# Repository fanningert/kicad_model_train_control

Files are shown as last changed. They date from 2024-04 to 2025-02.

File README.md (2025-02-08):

# Model Train Control

Control unit for analog model trains, based on ESPHome. A Home Assistant instance is used for visualization and control. This board is stackable up to 64 boards and every board has 16 outputs (3 pin). The Voltage is limited on the outputs per ESPHome template.
It comes in three variants, but all variants are the same boards. Only some components are not placed.

* Primary node with ESP32-S3-Wroom-2
* Primary node with ESP32-Devkit (can also be used as sub node with 3,3V power supply and protection)
* Sub node

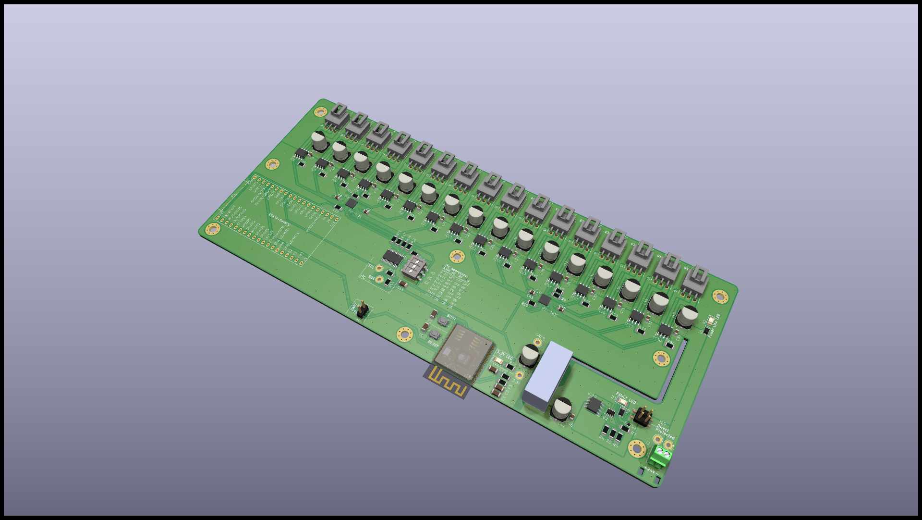
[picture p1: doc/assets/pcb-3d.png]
3D render of PCB

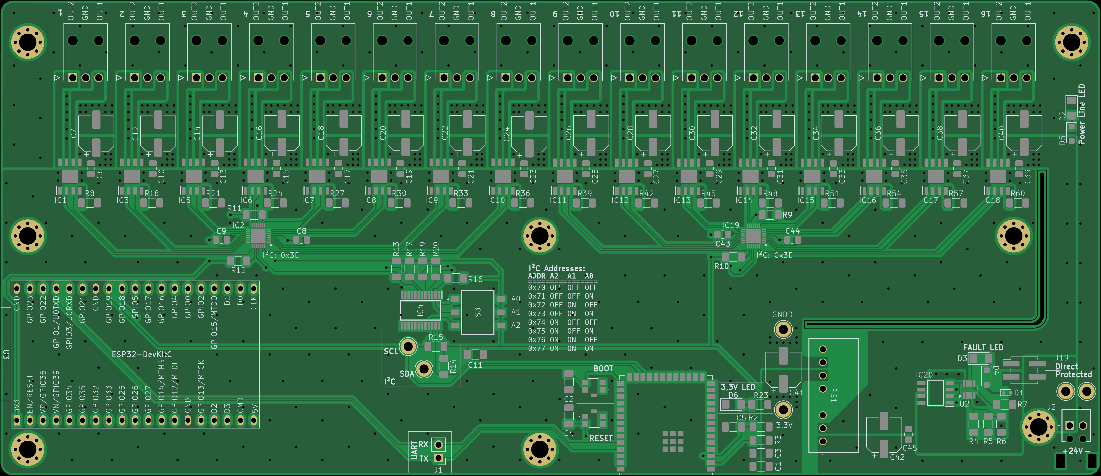
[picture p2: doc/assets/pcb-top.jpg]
PCB Top

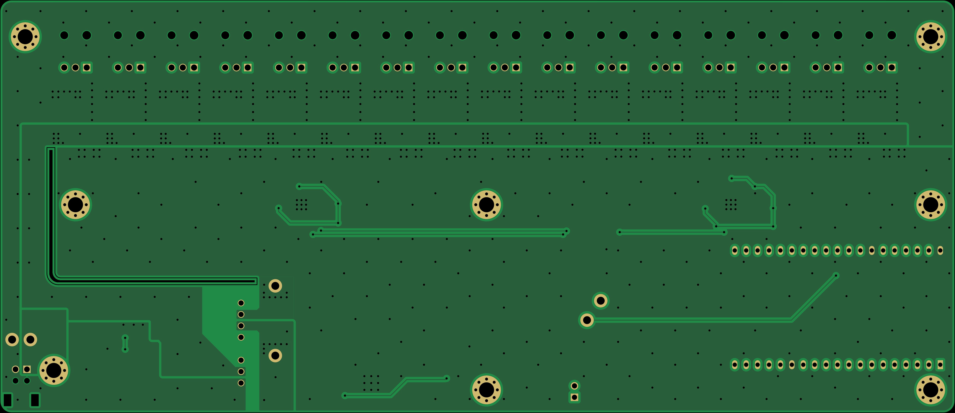
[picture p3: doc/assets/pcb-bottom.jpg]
PCB Bottom


## Features

* 16 h-bridges per board and stackable to 64 boards
* Reverse Voltage, Over Voltage and Under Voltage protection
* (optional) ESP32-Devkit
* (optional) ESP32-S3-Wroom-2

## Simple graphic of the board connections

```mermaid
flowchart LR
    Z[PowerSupply] ===|24V DC| A
    A[PCB_Core1] ===|24V DC, 3.3V, I2C| B & C & D
    B[PCB_Core2]
    C[PCB_Core...]
    D[PCB_Core64]
```

## Supported szenarios

- Power line
- Yield
- Generic Switch
- Signal
- Uncoupler

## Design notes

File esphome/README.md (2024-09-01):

# Model Train Control - ESPHome configuration examples

There is a non linear curve for the voltage control. On step line from 0 to 5V in the first 5% and then a linear line up to the input voltage. One side effect of DRV8871DDA.

Input voltage: 24V DC
| Percent | Output Voltage |
|---|---|
| 0 | 0 |
| 10 | 6,5 V |
| 20 | 8,6 V |
| 30 | 10,7 V |
| 40 | 12,6 V |
| 50 | 14,6 V |
| 60 | 16,5 V |
| 70 | 18,4 V |
| 80 | 20,1 V |
| 90 | 22 V |
| 100 | 24 V |

For example, when you need 16V I selected 0,58 (58%) for the voltage_multi parameter.

## Templates

### Board

The central component for ESPHome usage. This create some internal components with unique IDs. When you stack the boards, you need to add one entry for every board with a unique board number.

Parameter:

* hub_no = every stack get it's unique id
* board_no = every board in the same stack get it's unique id

Usable output IDs like h1b1p1.
h = hub, b = board, p = Board Port

```yaml
packages:
  board1: !include
    file: common/mtc_ha_board.yaml
    vars:
      hub_no: 1
      board_no: 1
      i2c_address: "0x70"
  board2: !include
    file: common/mtc_ha_board.yaml
    vars:
      hub_no: 1
      board_no: 2
      i2c_address: "0x71"
```

### Power line

A simple H-Bridge to control the railway power of the train.

```yaml
packages:
  train01: !include
    file: common/mtc_ha_power_line.yaml
    vars:
      hub_no: ${hub_no}
      board_no: "1"
      port_no: "01"
      voltage_multi: 0.58
```

### Yield

```yaml
packages:
  yield01: !include
    file: common/mtc_ha_yield.yaml
    vars:
      hub_no: 1
      board_no: "1"
      port_no: "02"
      voltage_multi: 0.58
```

### Generic Switch

```yaml
packages:
  switch01: !include
    file: common/mtc_ha_switch.yaml
    vars:
      hub_no: 1
      board_no: "1"
      port_no: "03"
      voltage_multi: 0.58
```

### Signal

```yaml
packages:
  signal01: !include
    file: common/mtc_ha_signal.yaml
    vars:
      hub_no: 1
      board_no: "1"
      port_no: "04"
      voltage_multi: 0.58
```

### Decoupler

```yaml
packages:
  decoupler01: !include
    file: common/mtc_ha_decoupler.yaml
    vars:
      hub_no: 1
      board_no: "1"
      port_no: "05"
      voltage_multi: 0.58
```

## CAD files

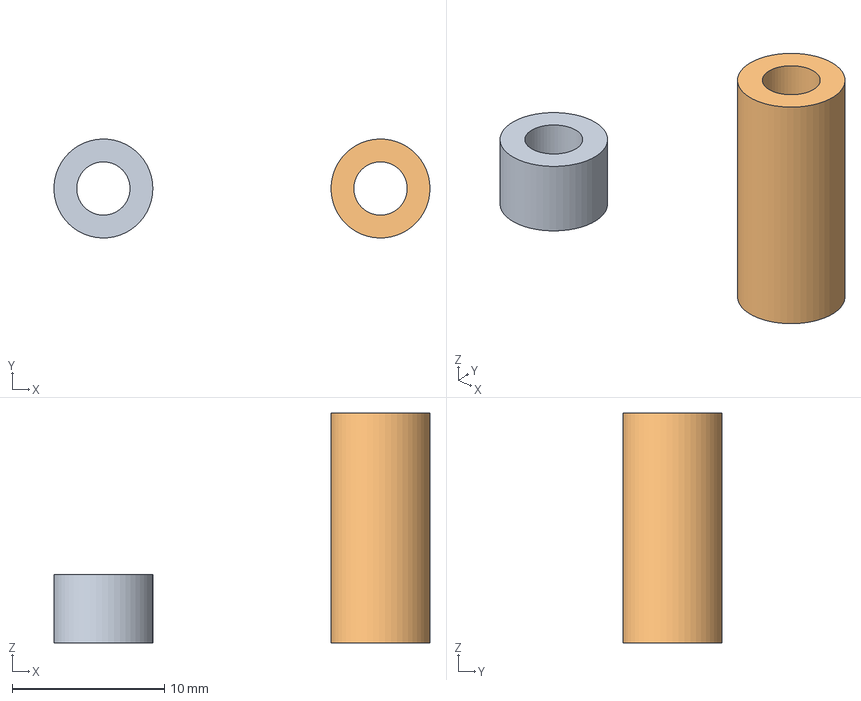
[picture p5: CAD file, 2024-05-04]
3dcase/case-Spacer.step
24.7 x 6.50 x 15.1 mm
Körper027
Körper032

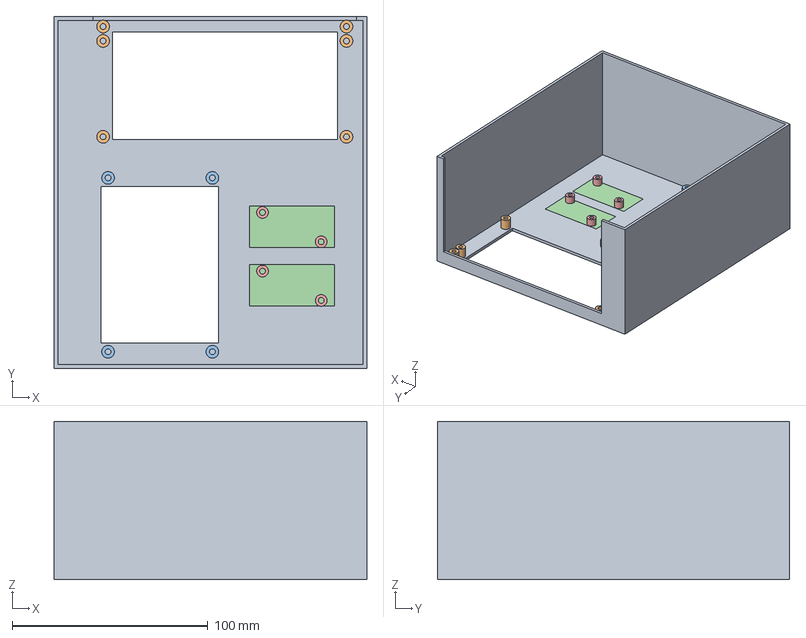
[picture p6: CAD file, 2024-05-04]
3dcase/case.step
160.0 x 180.0 x 81.0 mm
Körper007
Körper001
Körper002
Körper003
Körper004
Körper005
Körper006
Körper009
Körper010
Körper011
Körper012
Körper013
Körper014
Körper015
Körper016
Körper017
Körper018

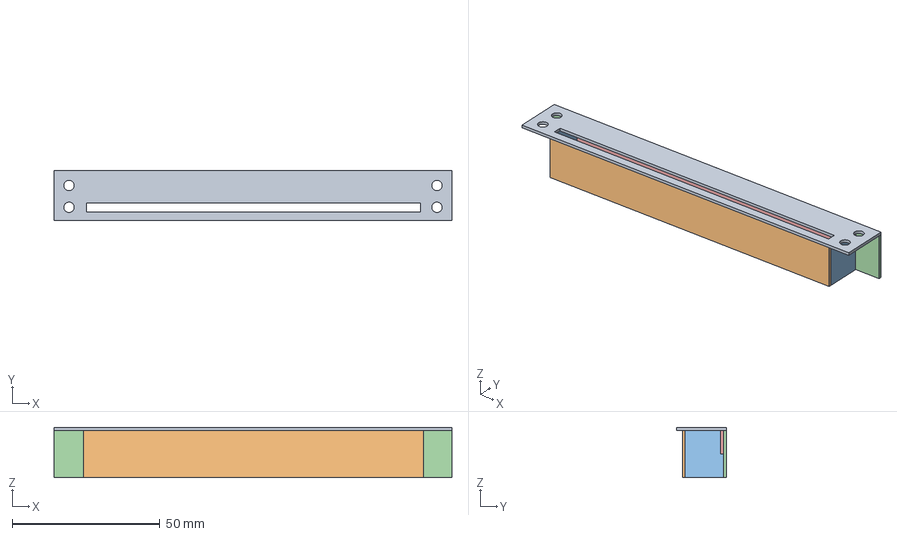
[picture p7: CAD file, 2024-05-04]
3dcase/case-PCBPlaceholder.step
134.6 x 17.0 x 17.0 mm
Körper020
Körper
Körper028
Körper029
Körper030
Körper031
Körper033

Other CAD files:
3dcase/case.FCStd

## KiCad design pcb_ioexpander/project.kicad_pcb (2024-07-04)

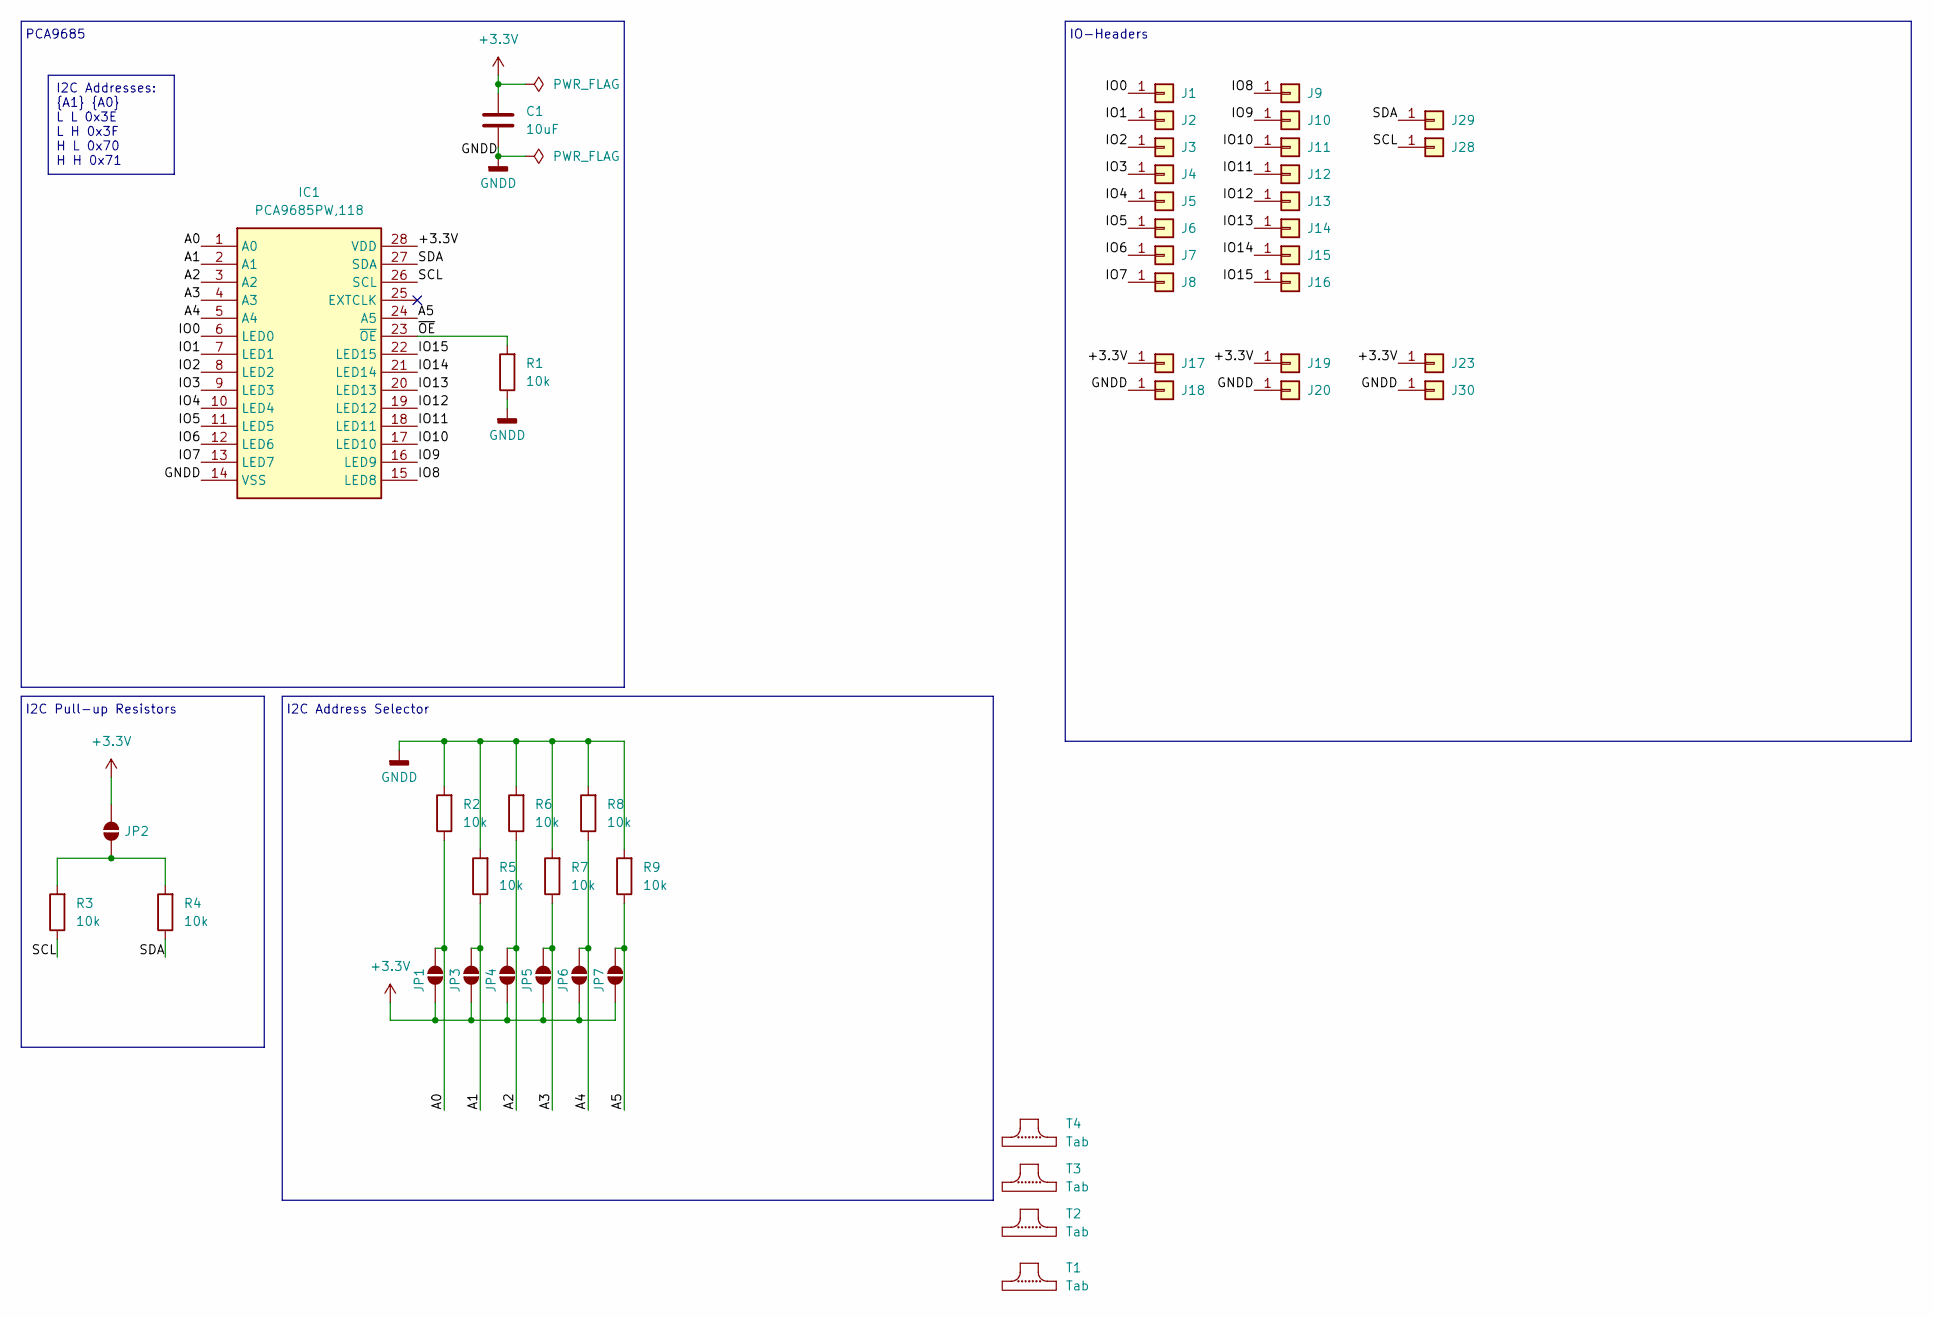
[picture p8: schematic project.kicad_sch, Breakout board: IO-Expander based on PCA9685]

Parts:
C1: 10uF; C_0402_1005Metric_Pad0.74x0.62mm_HandSolder
IC1: PCA9685PW,118; SOP65P640X110-28N; Mouser Part Number 771-PCA9685PW,118
J1, J2, J3, J4, J5, J6, J7, J8, J9, J10, J11, J12, J13, J14, J15, J16, J17, J18, J19, J20, J23, J28, J29, J30: Castellated_Hole02
JP1, JP2, JP3, JP4, JP5, JP6, JP7: SolderJumper_2_Open; SolderJumper-2_P1.3mm_Open_TrianglePad1.0x1.5mm
R1, R2, R3, R4, R5, R6, R7, R8, R9: 10k; R_0402_1005Metric_Pad0.72x0.64mm_HandSolder
T1, T2, T3, T4: Tab

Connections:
+3.3V: C1.1, IC1.28 (VDD), J17.1, J19.1, J23.1, JP1.2 (B), JP2.2 (B), JP3.2 (B), JP4.2 (B), JP5.2 (B), JP6.2 (B), JP7.2 (B)
/A0: IC1.1 (A0), JP1.1 (A), R2.1
/A1: IC1.2 (A1), JP3.1 (A), R5.1
/A2: IC1.3 (A2), JP4.1 (A), R6.1
/A3: IC1.4 (A3), JP5.1 (A), R7.1
/A4: IC1.5 (A4), JP6.1 (A), R8.1
/A5: IC1.24 (A5), JP7.1 (A), R9.1
/IO0: IC1.6 (LED0), J1.1
/IO1: IC1.7 (LED1), J2.1
/IO2: IC1.8 (LED2), J3.1
/IO3: IC1.9 (LED3), J4.1
/IO4: IC1.10 (LED4), J5.1
/IO5: IC1.11 (LED5), J6.1
/IO6: IC1.12 (LED6), J7.1
/IO7: IC1.13 (LED7), J8.1
/IO8: IC1.15 (LED8), J9.1
/IO9: IC1.16 (LED9), J10.1
/IO10: IC1.17 (LED10), J11.1
/IO11: IC1.18 (LED11), J12.1
/IO12: IC1.19 (LED12), J13.1
/IO13: IC1.20 (LED13), J14.1
/IO14: IC1.21 (LED14), J15.1
/IO15: IC1.22 (LED15), J16.1
/SCL: IC1.26 (SCL), J28.1, R3.1
/SDA: IC1.27 (SDA), J29.1, R4.1
/~OE: IC1.23 (~OE), R1.2
GNDD: C1.2, IC1.14 (VSS), J18.1, J20.1, J30.1, R1.1, R2.2, R5.2, R6.2, R7.2, R8.2, R9.2
unnamed: JP2.1 (A), R3.2, R4.2

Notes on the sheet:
I2C Addresses: {A1} {A0} L L 0x3E L H 0x3F H L 0x70 H H 0x71
IO-Headers
I2C Address Selector
I2C Pull-up Resistors
PCA9685

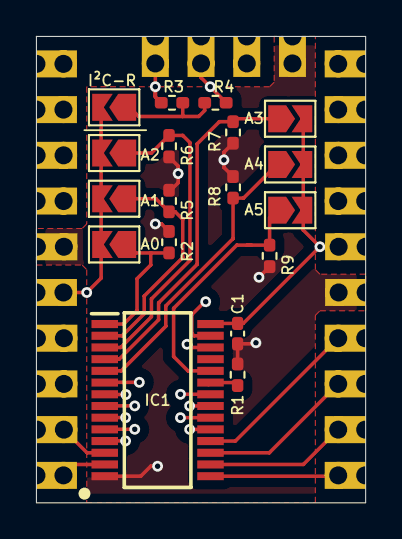
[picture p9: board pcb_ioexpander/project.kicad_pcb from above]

Board: 4 copper layers, 18.3 x 25.9 mm, 47 parts (1 on the bottom side), 28 nets.

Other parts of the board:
QR*****: https://github.com/fanningert/kicad_pcb_ioexpander; //github.com/fanningert/kicad_pcb_ioexpander

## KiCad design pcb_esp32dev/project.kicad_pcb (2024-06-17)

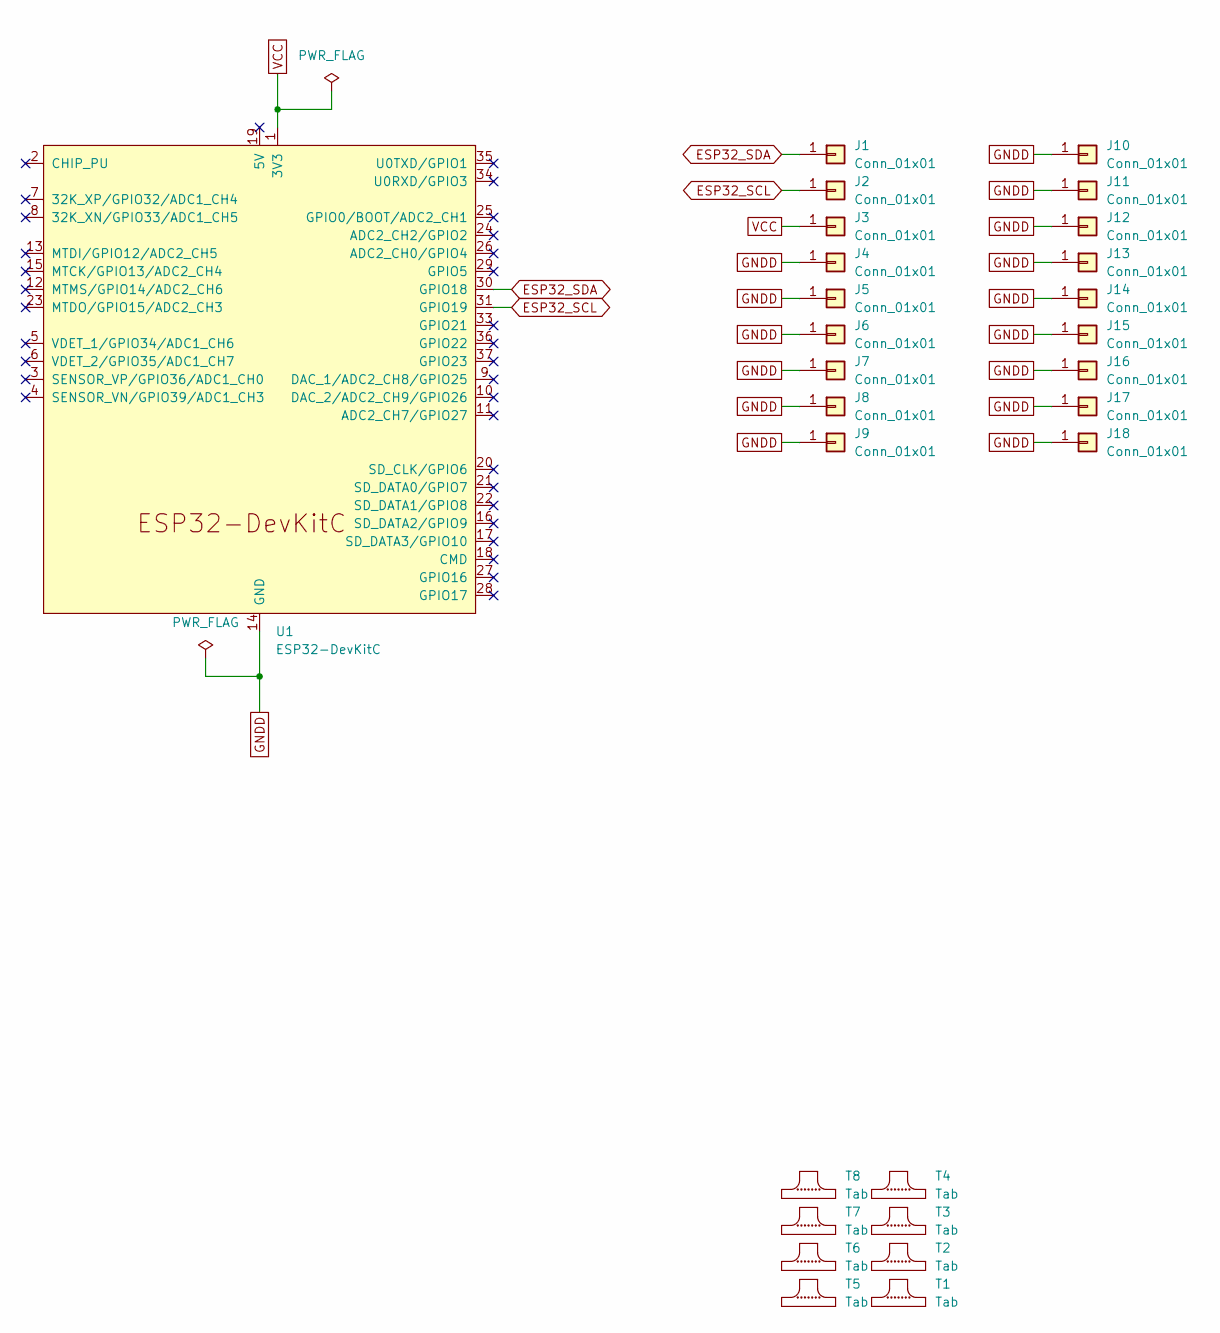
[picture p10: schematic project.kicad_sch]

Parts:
J1, J2, J3, J4, J5, J6, J7, J8, J9, J10, J11, J12, J13, J14, J15, J16, J17, J18: Conn_01x01; Castellated_Hole02
T1, T2, T3, T4, T5, T6, T7, T8: Tab
U1: ESP32-DevKitC

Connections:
ESP32_SCL: J2.1, U1.31 (GPIO19)
ESP32_SDA: J1.1, U1.30 (GPIO18)
GNDD: J4.1, J5.1, J6.1, J7.1, J8.1, J9.1, J10.1, J11.1, J12.1, J13.1, J14.1, J15.1, J16.1, J17.1, J18.1, U1.14 (GND), U1.32 (GND), U1.38 (GND)
VCC: J3.1, U1.1 (3V3)

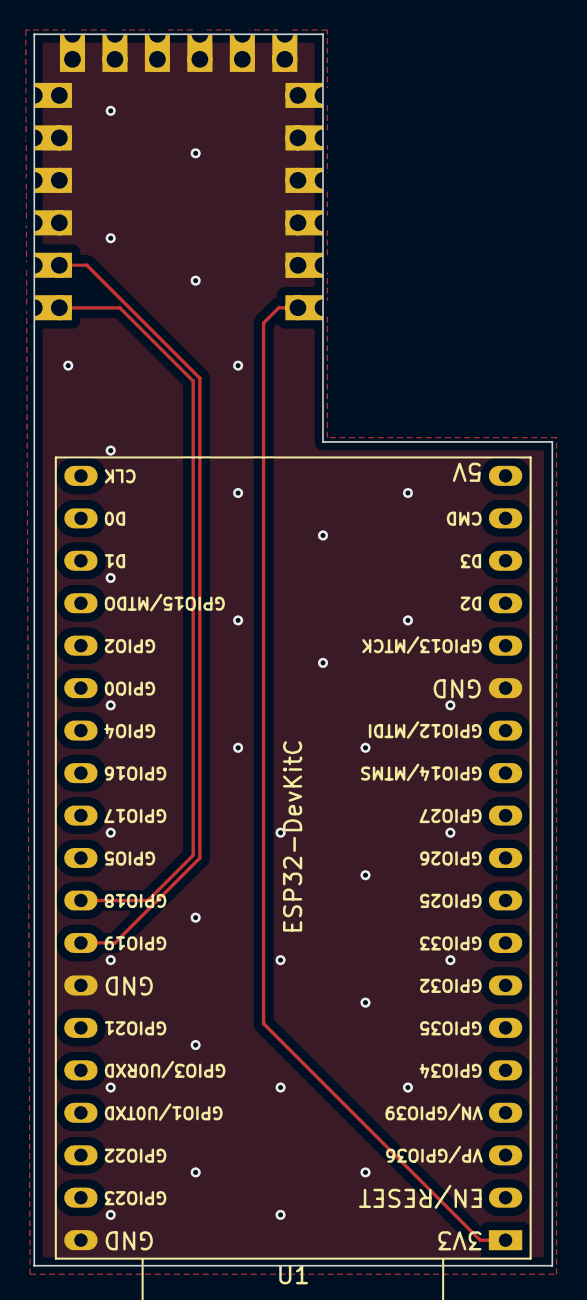
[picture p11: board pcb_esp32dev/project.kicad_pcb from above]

Board: 2 copper layers, 31.0 x 73.7 mm, 27 parts (0 on the bottom side), 4 nets.

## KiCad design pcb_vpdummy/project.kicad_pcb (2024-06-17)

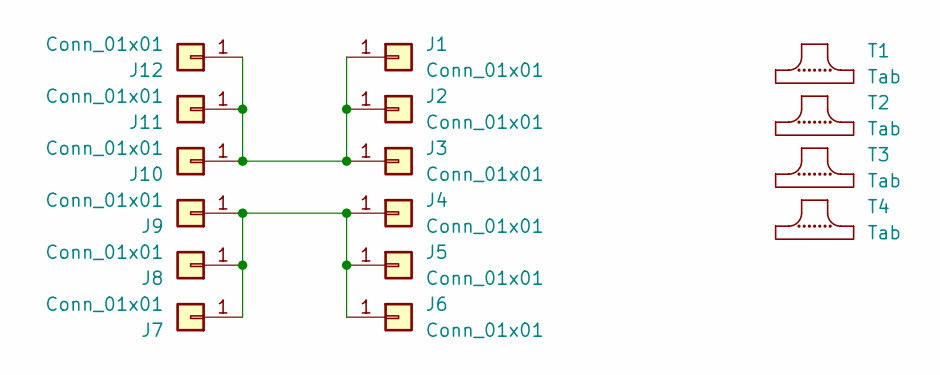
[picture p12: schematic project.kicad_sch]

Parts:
J1, J2, J3, J4, J5, J6, J7, J8, J9, J10, J11, J12: Conn_01x01; Castellated_Hole02
T1, T2, T3, T4: Tab

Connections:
unnamed: J1.1, J2.1, J3.1, J10.1, J11.1, J12.1
unnamed: J4.1, J5.1, J6.1, J7.1, J8.1, J9.1

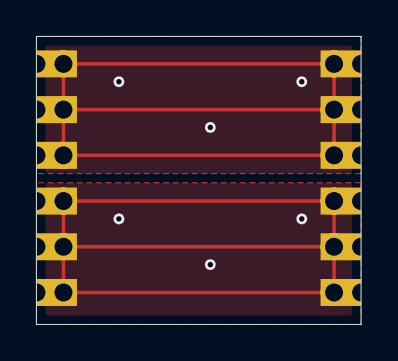
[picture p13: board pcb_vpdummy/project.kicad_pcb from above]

Board: 2 copper layers, 18.0 x 16.0 mm, 16 parts (0 on the bottom side), 2 nets.

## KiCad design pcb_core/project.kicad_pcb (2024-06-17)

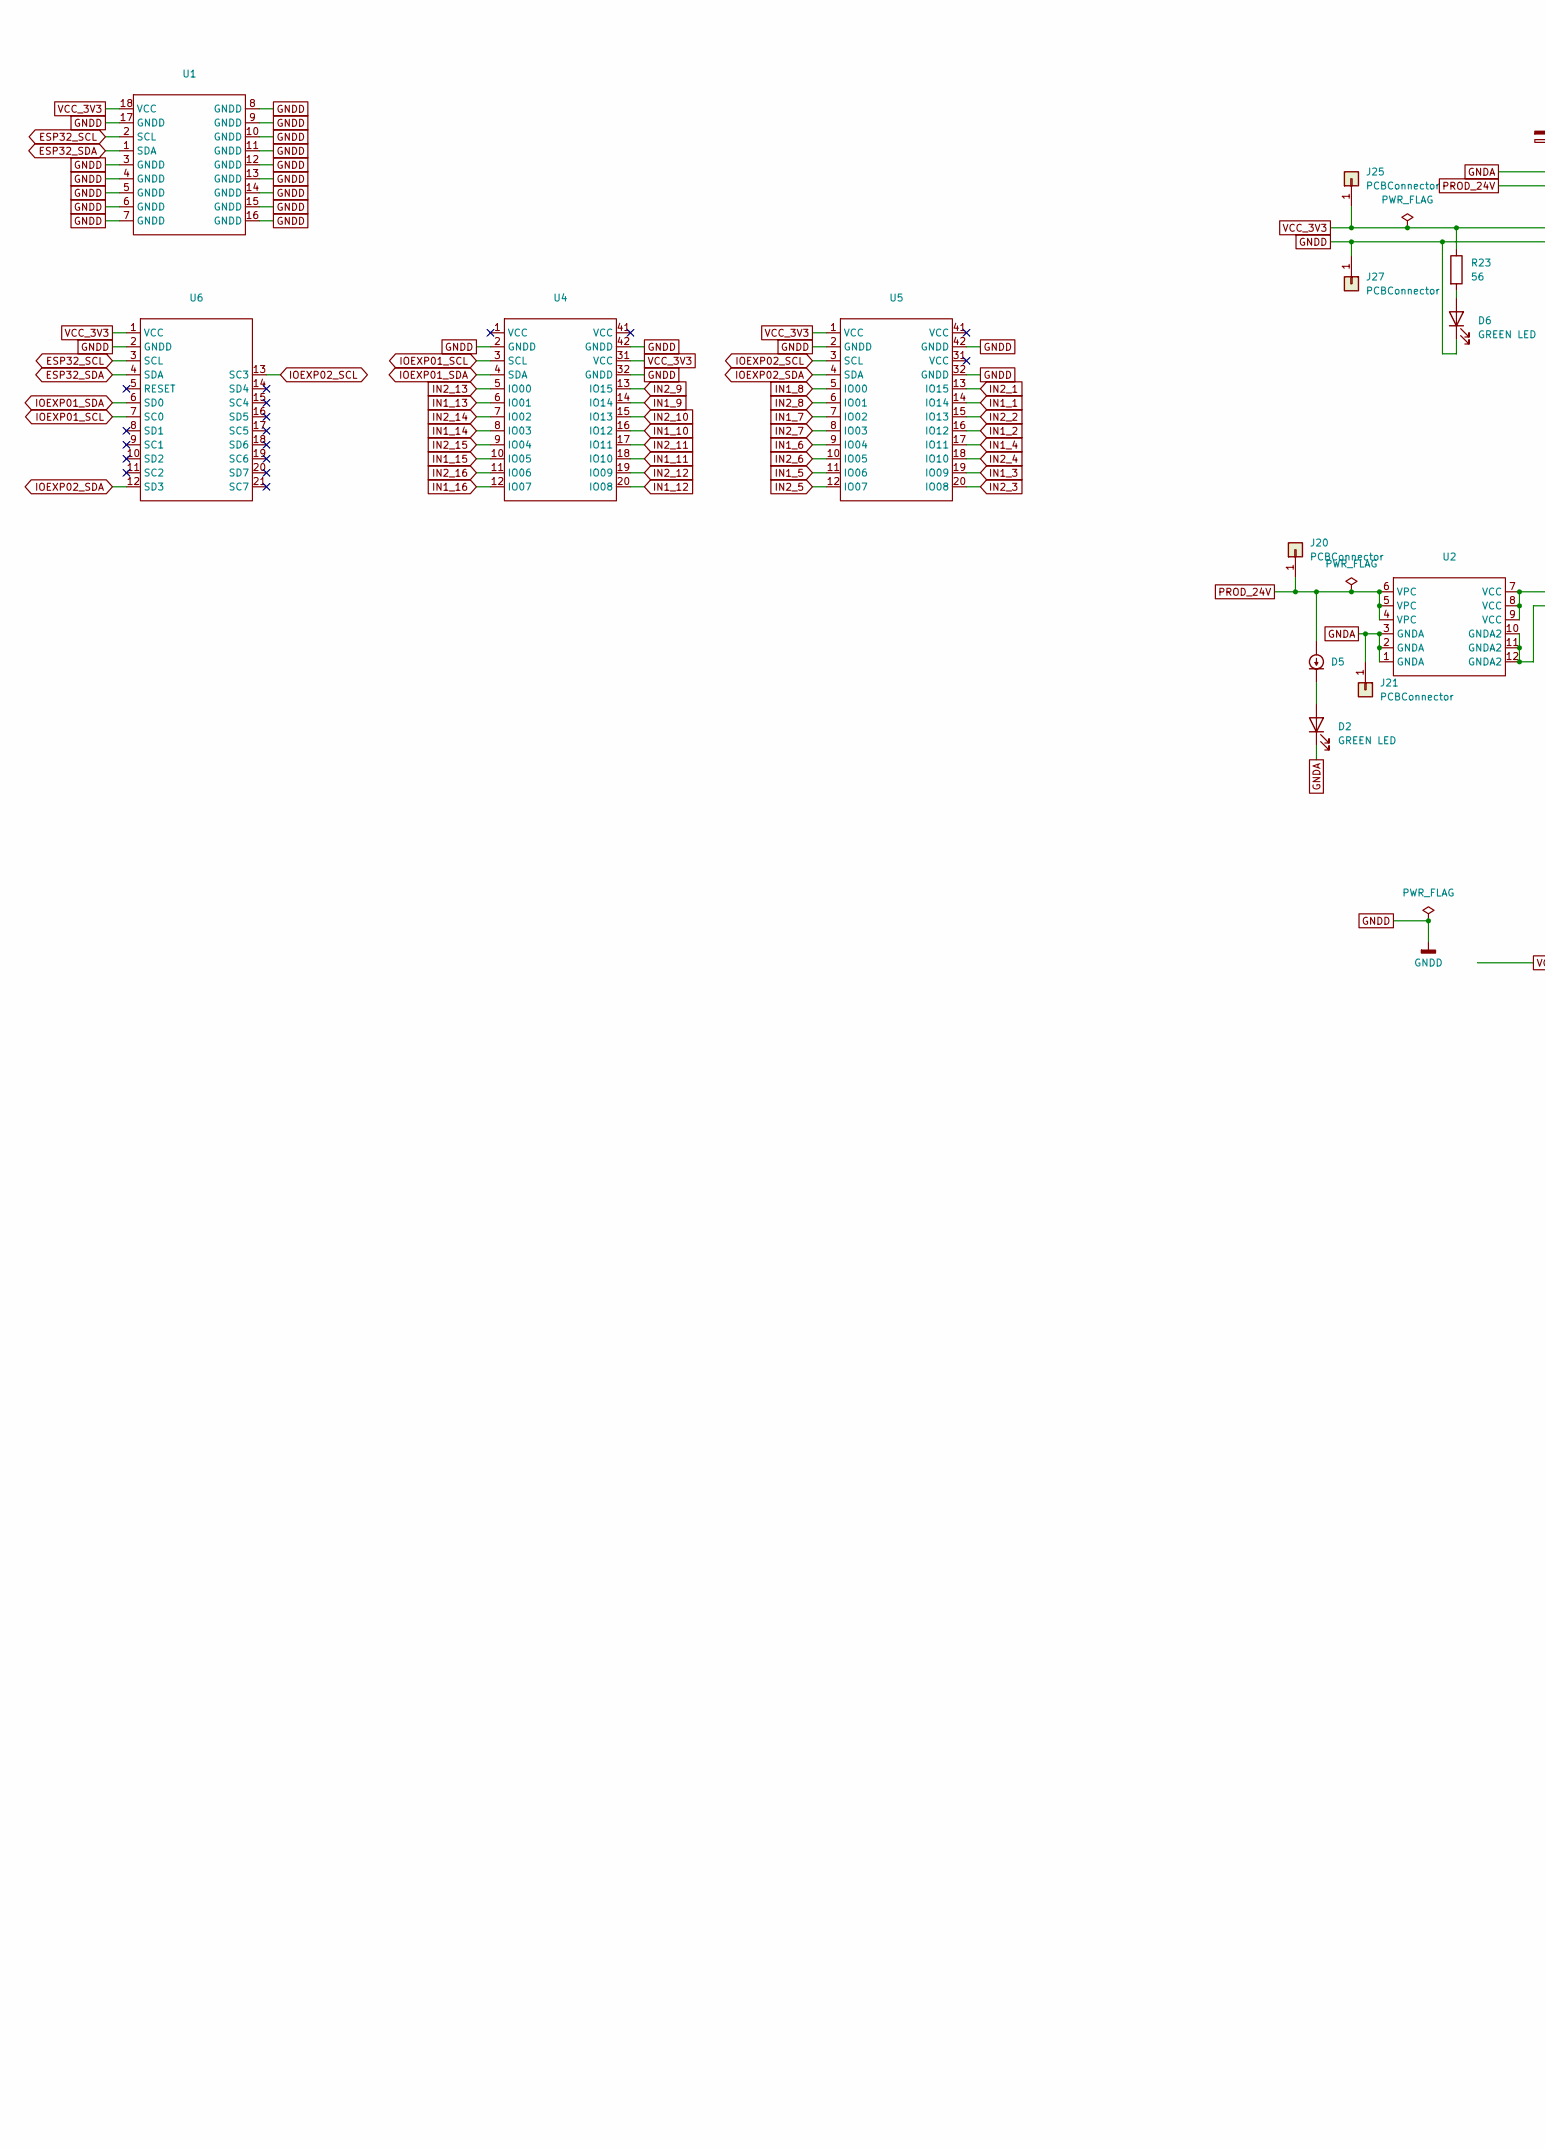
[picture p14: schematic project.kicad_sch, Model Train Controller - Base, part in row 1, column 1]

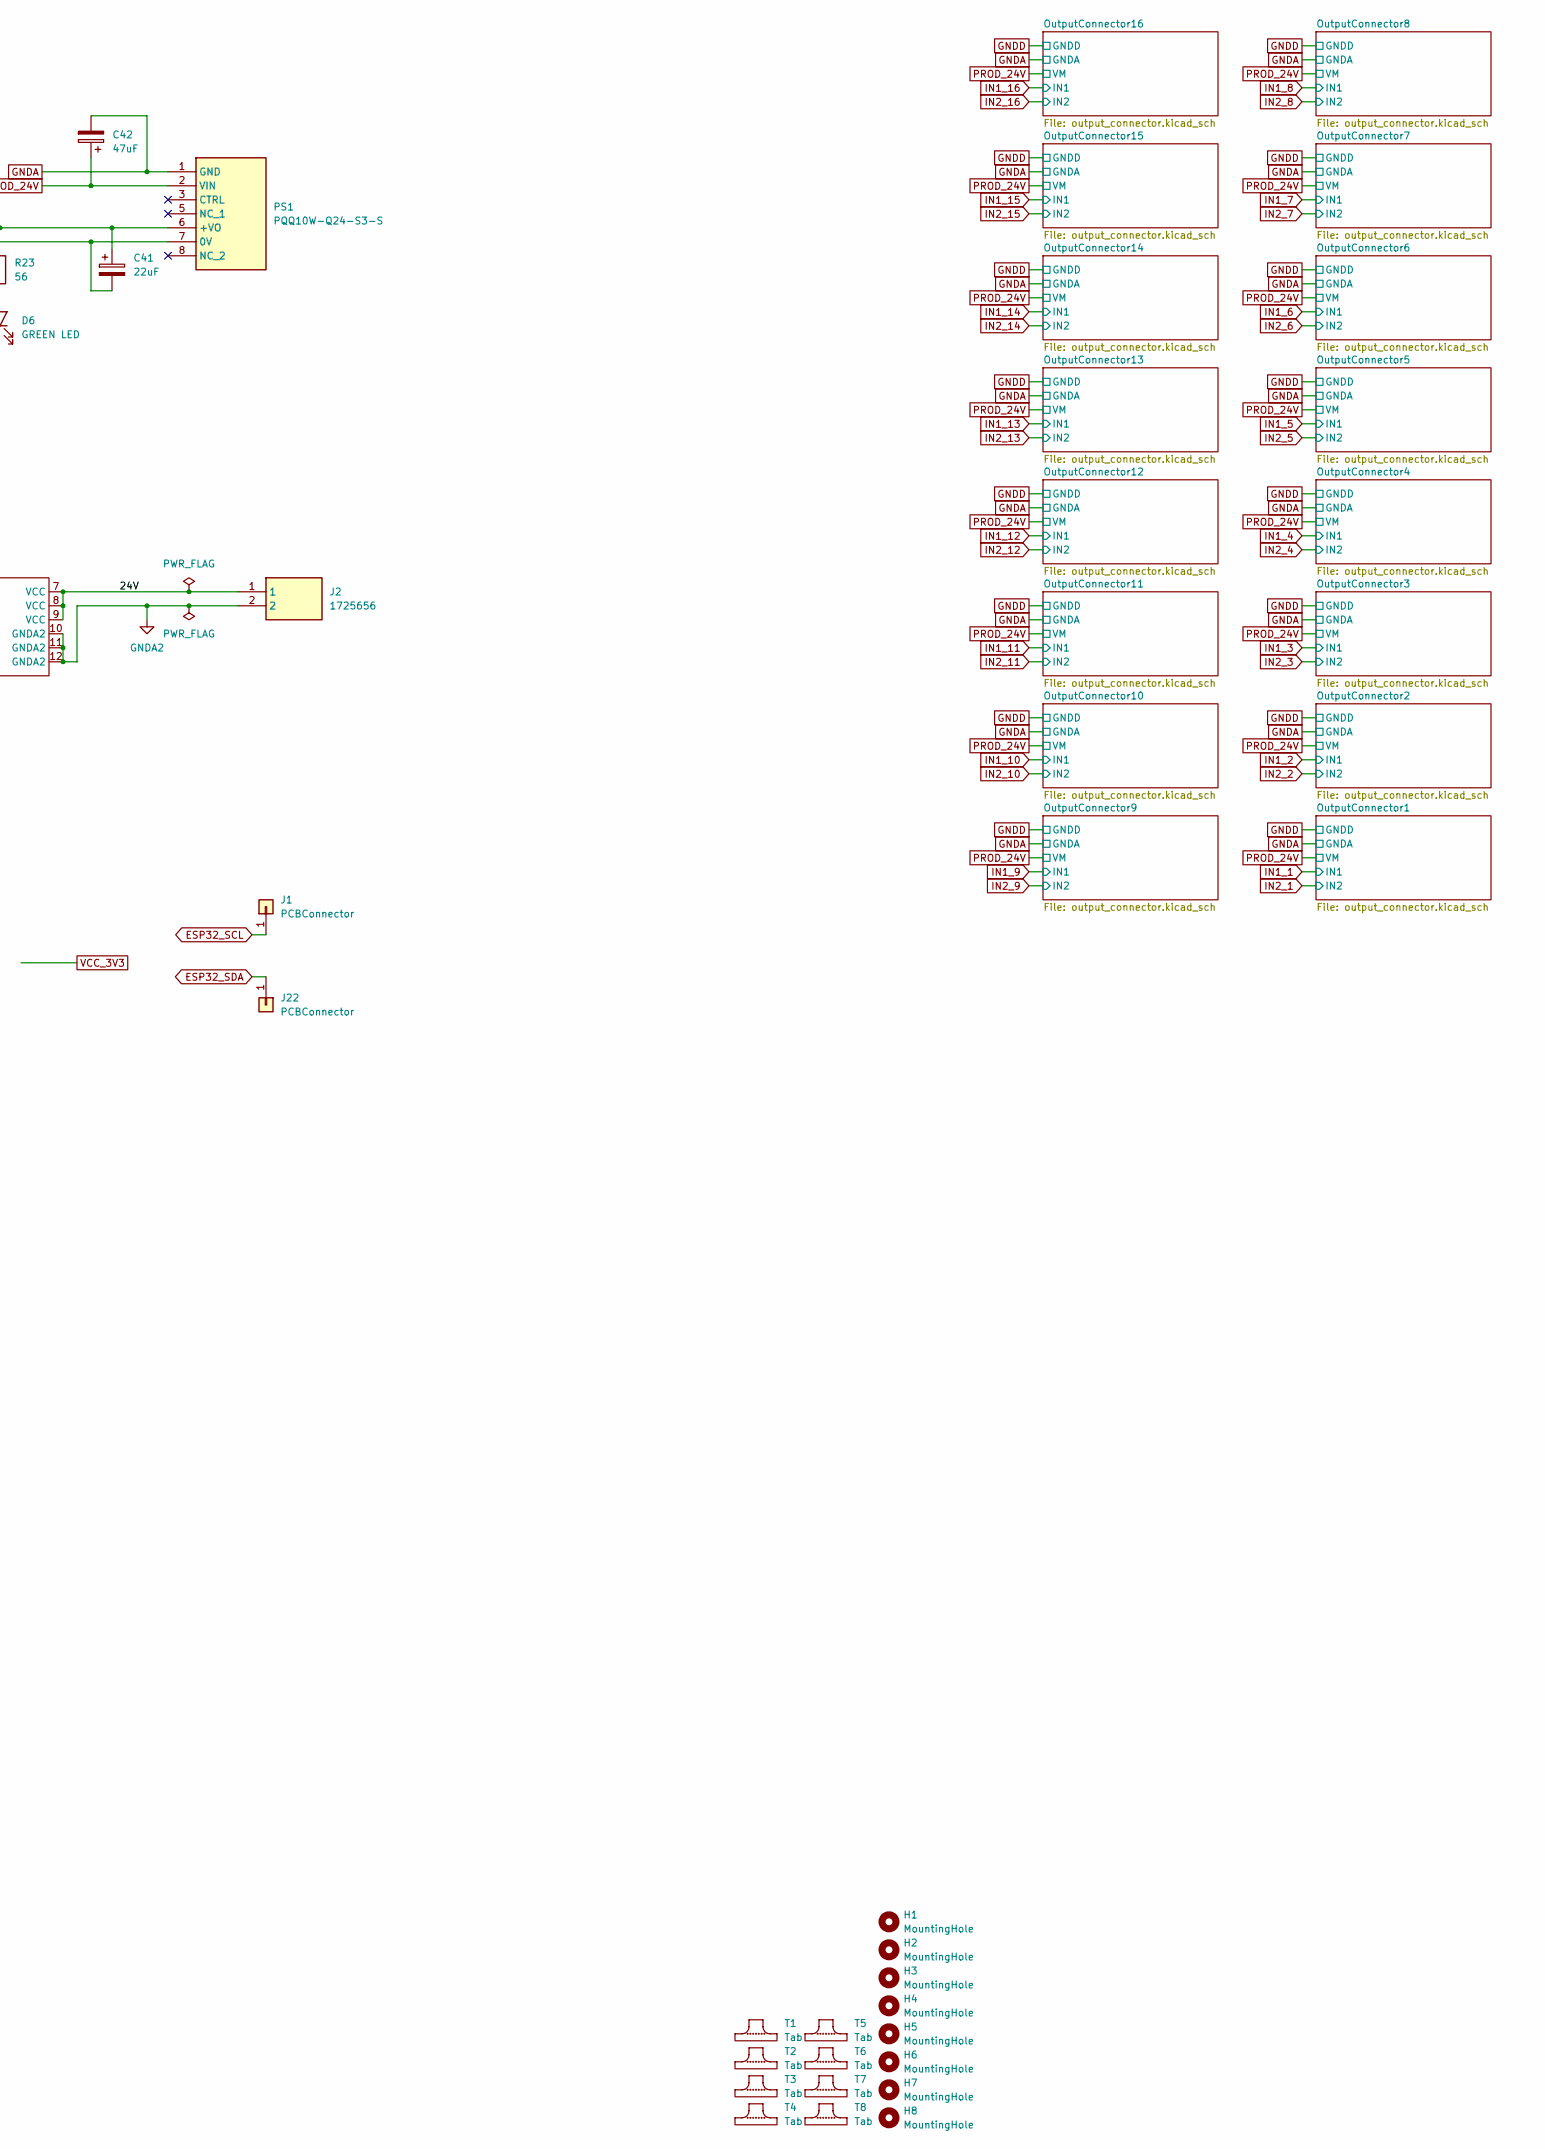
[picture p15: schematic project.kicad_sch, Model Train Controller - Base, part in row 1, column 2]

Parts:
C41: 22uF; CP_Elec_6.3x7.7; Manufacturer_Part_Number Polarized Capacitor, 22.0uF, 63V, D6.3x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; LCSC# C5246567
C42: 47uF; CP_Elec_6.3x7.7; Manufacturer_Part_Number FZ47UF35V90RV0124; LCSC# C267471
D2, D6: GREEN LED; LED_1206_3216Metric_Pad1.42x1.75mm_HandSolder; Manufacturer_Part_Number SML-012P8TT86; LCSC# C5336737
D5: D_SOD-123F; Manufacturer_Part_Number CMJ2000 TR PBFREE; Mouser Part Number 610-CMJ2000TR
H1, H2, H3, H4, H5, H6, H7, H8: MountingHole; MountingHole_3.2mm_M3_Pad_Via
J1, J20, J21, J22, J25, J27: PCBConnector; TestPoint_THTPad_D3.0mm_Drill1.5mm
J2: 1725656; Mouser Part Number 651-1725656
PS1: PQQ10W-Q24-S3-S; PQQ10WQ24S3S; Mouser Part Number 490-PQQ10W-Q24-S3-S
R23: 56; R_1206_3216Metric_Pad1.30x1.75mm_HandSolder; Mouser Part Number 71-CRCW1206-56-E3; LCSC# C2933788
T1, T2, T3, T4, T5, T6, T7, T8: Tab
U1: esp32
U2: voltage_protection
U4, U5: ioexpander
U6: i2cmultiplexer

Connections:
/24V: J2.1, U2.7 (VCC), U2.8 (VCC), U2.9 (VCC)
ESP32_SCL: J1.1, U1.2 (SCL), U6.3 (SCL)
ESP32_SDA: J22.1, U1.1 (SDA), U6.4 (SDA)
GNDA: C42.2, D2.1 (K), J21.1, PS1.1 (GND), U2.1 (GNDA), U2.2 (GNDA), U2.3 (GNDA); also elsewhere on the board
GNDA2: J2.2, U2.10 (GNDA2), U2.11 (GNDA2), U2.12 (GNDA2)
GNDD: C41.2, D6.1 (K), J27.1, PS1.7 (0V), U1.3 (GNDD), U1.4 (GNDD), U1.5 (GNDD), U1.6 (GNDD), U1.7 (GNDD), U1.8 (GNDD), U1.9 (GNDD), U1.10 (GNDD), U1.11 (GNDD), U1.12 (GNDD), U1.13 (GNDD), U1.14 (GNDD), U1.15 (GNDD), U1.16 (GNDD), U1.17 (GNDD), U4.2 (GNDD), U4.32 (GNDD), U4.42 (GNDD), U5.2 (GNDD), U5.32 (GNDD), U5.42 (GNDD), U6.2 (GNDD); also elsewhere on the board
IN1_1: U5.14 (IO14); also elsewhere on the board
IN1_2: U5.16 (IO12); also elsewhere on the board
IN1_3: U5.19 (IO09); also elsewhere on the board
IN1_4: U5.17 (IO11); also elsewhere on the board
IN1_5: U5.11 (IO06); also elsewhere on the board
IN1_6: U5.9 (IO04); also elsewhere on the board
IN1_7: U5.7 (IO02); also elsewhere on the board
IN1_8: U5.5 (IO00); also elsewhere on the board
IN1_9: U4.14 (IO14); also elsewhere on the board
IN1_10: U4.16 (IO12); also elsewhere on the board
IN1_11: U4.18 (IO10); also elsewhere on the board
IN1_12: U4.20 (IO08); also elsewhere on the board
IN1_13: U4.6 (IO01); also elsewhere on the board
IN1_14: U4.8 (IO03); also elsewhere on the board
IN1_15: U4.10 (IO05); also elsewhere on the board
IN1_16: U4.12 (IO07); also elsewhere on the board
IN2_1: U5.13 (IO15); also elsewhere on the board
IN2_2: U5.15 (IO13); also elsewhere on the board
IN2_3: U5.20 (IO08); also elsewhere on the board
IN2_4: U5.18 (IO10); also elsewhere on the board
IN2_5: U5.12 (IO07); also elsewhere on the board
IN2_6: U5.10 (IO05); also elsewhere on the board
IN2_7: U5.8 (IO03); also elsewhere on the board
IN2_8: U5.6 (IO01); also elsewhere on the board
IN2_9: U4.13 (IO15); also elsewhere on the board
IN2_10: U4.15 (IO13); also elsewhere on the board
IN2_11: U4.17 (IO11); also elsewhere on the board
IN2_12: U4.19 (IO09); also elsewhere on the board
IN2_13: U4.5 (IO00); also elsewhere on the board
IN2_14: U4.7 (IO02); also elsewhere on the board
IN2_15: U4.9 (IO04); also elsewhere on the board
IN2_16: U4.11 (IO06); also elsewhere on the board
IOEXP01_SCL: U4.3 (SCL), U6.7 (SC0)
IOEXP01_SDA: U4.4 (SDA), U6.6 (SD0)
IOEXP02_SCL: U5.3 (SCL), U6.13 (SC3)
IOEXP02_SDA: U5.4 (SDA), U6.12 (SD3)
unnamed: D2.2 (A), D5.1 (K)
unnamed: D6.2 (A), R23.2
PROD_24V: C42.1, D5.2 (A), J20.1, PS1.2 (VIN), U2.4 (VPC), U2.5 (VPC), U2.6 (VPC); also elsewhere on the board
VCC_3V3: C41.1, J25.1, PS1.6 (+VO), R23.1, U1.18 (VCC), U4.31 (VCC), U5.1 (VCC), U6.1 (VCC)

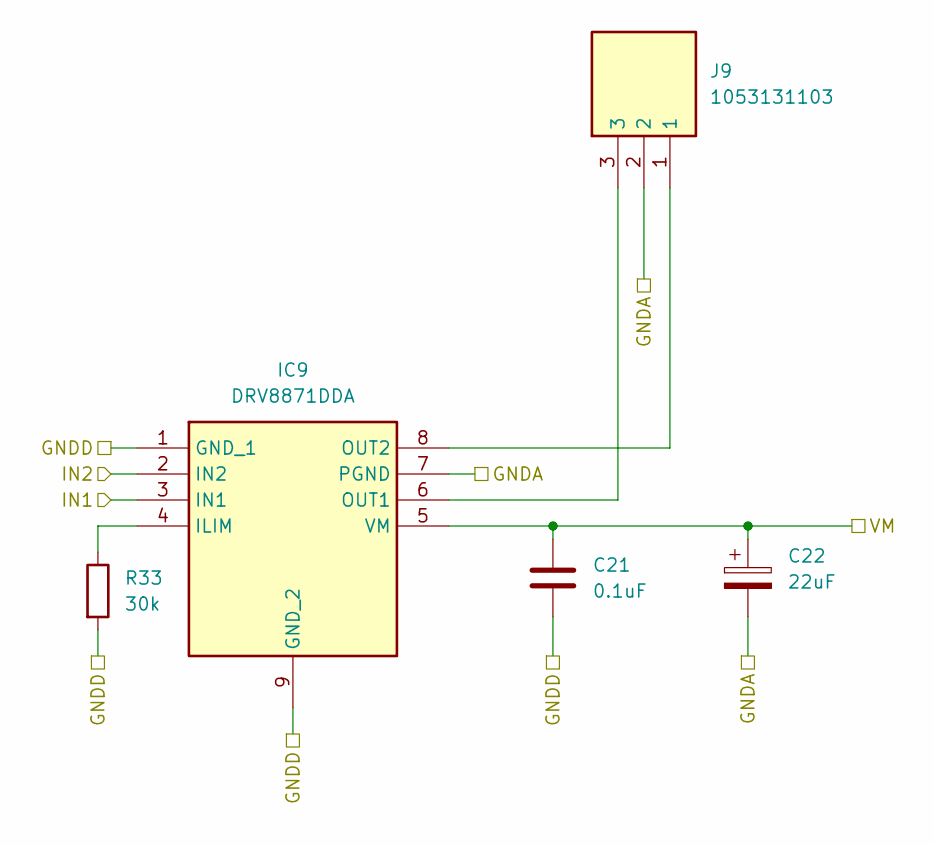
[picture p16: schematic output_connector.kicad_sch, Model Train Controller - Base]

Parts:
C21: 0.1uF; C_0805_2012Metric_Pad1.18x1.45mm_HandSolder; Manufacturer_Part_Number Capacitor, 0.1uF, 50V, 0805 SMD; LCSC# C49678
C22: 22uF; CP_Elec_6.3x7.7; Manufacturer_Part_Number Polarized Capacitor, 22.0uF, 63V, D6.3x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; LCSC# C5246567
IC9: DRV8871DDA; SOIC127P600X170-9N; Manufacturer_Part_Number DRV8871DDA; LCSC# C1556867
J9: 1053131103; 105313YY03; Manufacturer_Part_Number 1053131103; Mouser Part Number 538-105313-1103
R33: 30k; R_1206_3216Metric_Pad1.30x1.75mm_HandSolder; Mouser Part Number 652-CR1206FX-3002ELF; LCSC# C2907479

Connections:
GNDA: C22.2, IC9.7 (PGND), J9.2; also elsewhere on the board
GNDD: C21.2, IC9.1 (GND_1), IC9.9 (GND_2), R33.2; also elsewhere on the board
IN1_7: IC9.3 (IN1); also elsewhere on the board
IN2_7: IC9.2 (IN2); also elsewhere on the board
unnamed: IC9.4 (ILIM), R33.1
unnamed: IC9.6 (OUT1), J9.3
unnamed: IC9.8 (OUT2), J9.1
PROD_24V: C21.1, C22.1, IC9.5 (VM); also elsewhere on the board

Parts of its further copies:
C6, C10, C13, C15, C17, C19, C23, C25, C27, C29, C31, C33, C35, C37, C39: 0.1uF; C_0805_2012Metric_Pad1.18x1.45mm_HandSolder; Manufacturer_Part_Number Capacitor, 0.1uF, 50V, 0805 SMD; LCSC# C49678
C7, C12, C14, C16, C18, C20, C24, C26, C28, C30, C32, C34, C36, C38, C40: 22uF; CP_Elec_6.3x7.7; Manufacturer_Part_Number Polarized Capacitor, 22.0uF, 63V, D6.3x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; LCSC# C5246567
IC1, IC3, IC5, IC6, IC7, IC8, IC10, IC11, IC12, IC13, IC14, IC15, IC16, IC17, IC18: DRV8871DDA; SOIC127P600X170-9N; Manufacturer_Part_Number DRV8871DDA; LCSC# C1556867
J3, J4, J5, J6, J7, J8, J10, J11, J12, J13, J14, J15, J16, J17, J18: 1053131103; 105313YY03; Manufacturer_Part_Number 1053131103; Mouser Part Number 538-105313-1103
R8, R18, R21, R24, R27, R30, R36, R39, R42, R45, R48, R51, R54, R57, R60: 30k; R_1206_3216Metric_Pad1.30x1.75mm_HandSolder; Mouser Part Number 652-CR1206FX-3002ELF; LCSC# C2907479

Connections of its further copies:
GNDA: C7.2, C12.2, C14.2, C16.2, C18.2, C20.2, C24.2, C26.2, C28.2, C30.2, C32.2, C34.2, C36.2, C38.2, C40.2, IC1.7 (PGND), IC3.7 (PGND), IC5.7 (PGND), IC6.7 (PGND), IC7.7 (PGND), IC8.7 (PGND), IC10.7 (PGND), IC11.7 (PGND), IC12.7 (PGND), IC13.7 (PGND), IC14.7 (PGND), IC15.7 (PGND), IC16.7 (PGND), IC17.7 (PGND), IC18.7 (PGND), J3.2, J4.2, J5.2, J6.2, J7.2, J8.2, J10.2, J11.2, J12.2, J13.2, J14.2, J15.2, J16.2, J17.2, J18.2; also elsewhere on the board
GNDD: C6.2, C10.2, C13.2, C15.2, C17.2, C19.2, C23.2, C25.2, C27.2, C29.2, C31.2, C33.2, C35.2, C37.2, C39.2, IC1.1 (GND_1), IC1.9 (GND_2), IC3.1 (GND_1), IC3.9 (GND_2), IC5.1 (GND_1), IC5.9 (GND_2), IC6.1 (GND_1), IC6.9 (GND_2), IC7.1 (GND_1), IC7.9 (GND_2), IC8.1 (GND_1), IC8.9 (GND_2), IC10.1 (GND_1), IC10.9 (GND_2), IC11.1 (GND_1), IC11.9 (GND_2), IC12.1 (GND_1), IC12.9 (GND_2), IC13.1 (GND_1), IC13.9 (GND_2), IC14.1 (GND_1), IC14.9 (GND_2), IC15.1 (GND_1), IC15.9 (GND_2), IC16.1 (GND_1), IC16.9 (GND_2), IC17.1 (GND_1), IC17.9 (GND_2), IC18.1 (GND_1), IC18.9 (GND_2), R8.2, R18.2, R21.2, R24.2, R27.2, R30.2, R36.2, R39.2, R42.2, R45.2, R48.2, R51.2, R54.2, R57.2, R60.2; also elsewhere on the board
IN1_1: IC1.3 (IN1); also elsewhere on the board
IN1_2: IC3.3 (IN1); also elsewhere on the board
IN1_3: IC5.3 (IN1); also elsewhere on the board
IN1_4: IC6.3 (IN1); also elsewhere on the board
IN1_5: IC7.3 (IN1); also elsewhere on the board
IN1_6: IC8.3 (IN1); also elsewhere on the board
IN1_8: IC10.3 (IN1); also elsewhere on the board
IN1_9: IC11.3 (IN1); also elsewhere on the board
IN1_10: IC12.3 (IN1); also elsewhere on the board
IN1_11: IC13.3 (IN1); also elsewhere on the board
IN1_12: IC14.3 (IN1); also elsewhere on the board
IN1_13: IC15.3 (IN1); also elsewhere on the board
IN1_14: IC16.3 (IN1); also elsewhere on the board
IN1_15: IC17.3 (IN1); also elsewhere on the board
IN1_16: IC18.3 (IN1); also elsewhere on the board
IN2_1: IC1.2 (IN2); also elsewhere on the board
IN2_2: IC3.2 (IN2); also elsewhere on the board
IN2_3: IC5.2 (IN2); also elsewhere on the board
IN2_4: IC6.2 (IN2); also elsewhere on the board
IN2_5: IC7.2 (IN2); also elsewhere on the board
IN2_6: IC8.2 (IN2); also elsewhere on the board
IN2_8: IC10.2 (IN2); also elsewhere on the board
IN2_9: IC11.2 (IN2); also elsewhere on the board
IN2_10: IC12.2 (IN2); also elsewhere on the board
IN2_11: IC13.2 (IN2); also elsewhere on the board
IN2_12: IC14.2 (IN2); also elsewhere on the board
IN2_13: IC15.2 (IN2); also elsewhere on the board
IN2_14: IC16.2 (IN2); also elsewhere on the board
IN2_15: IC17.2 (IN2); also elsewhere on the board
IN2_16: IC18.2 (IN2); also elsewhere on the board
unnamed: IC1.4 (ILIM), R8.1
unnamed: IC1.6 (OUT1), J3.3
unnamed: IC1.8 (OUT2), J3.1
unnamed: IC3.4 (ILIM), R18.1
unnamed: IC3.6 (OUT1), J4.3
unnamed: IC3.8 (OUT2), J4.1
unnamed: IC5.4 (ILIM), R21.1
unnamed: IC5.6 (OUT1), J5.3
unnamed: IC5.8 (OUT2), J5.1
unnamed: IC6.4 (ILIM), R24.1
unnamed: IC6.6 (OUT1), J6.3
unnamed: IC6.8 (OUT2), J6.1
unnamed: IC7.4 (ILIM), R27.1
unnamed: IC7.6 (OUT1), J7.3
unnamed: IC7.8 (OUT2), J7.1
unnamed: IC8.4 (ILIM), R30.1
unnamed: IC8.6 (OUT1), J8.3
unnamed: IC8.8 (OUT2), J8.1
unnamed: IC10.4 (ILIM), R36.1
unnamed: IC10.6 (OUT1), J10.3
unnamed: IC10.8 (OUT2), J10.1
unnamed: IC11.4 (ILIM), R39.1
unnamed: IC11.6 (OUT1), J11.3
unnamed: IC11.8 (OUT2), J11.1
unnamed: IC12.4 (ILIM), R42.1
unnamed: IC12.6 (OUT1), J12.3
unnamed: IC12.8 (OUT2), J12.1
unnamed: IC13.4 (ILIM), R45.1
unnamed: IC13.6 (OUT1), J13.3
unnamed: IC13.8 (OUT2), J13.1
unnamed: IC14.4 (ILIM), R48.1
unnamed: IC14.6 (OUT1), J14.3
unnamed: IC14.8 (OUT2), J14.1
unnamed: IC15.4 (ILIM), R51.1
unnamed: IC15.6 (OUT1), J15.3
unnamed: IC15.8 (OUT2), J15.1
unnamed: IC16.4 (ILIM), R54.1
unnamed: IC16.6 (OUT1), J16.3
unnamed: IC16.8 (OUT2), J16.1
unnamed: IC17.4 (ILIM), R57.1
unnamed: IC17.6 (OUT1), J17.3
unnamed: IC17.8 (OUT2), J17.1
unnamed: IC18.4 (ILIM), R60.1
unnamed: IC18.6 (OUT1), J18.3
unnamed: IC18.8 (OUT2), J18.1
PROD_24V: C6.1, C7.1, C10.1, C12.1, C13.1, C14.1, C15.1, C16.1, C17.1, C18.1, C19.1, C20.1, C23.1, C24.1, C25.1, C26.1, C27.1, C28.1, C29.1, C30.1, C31.1, C32.1, C33.1, C34.1, C35.1, C36.1, C37.1, C38.1, C39.1, C40.1, IC1.5 (VM), IC3.5 (VM), IC5.5 (VM), IC6.5 (VM), IC7.5 (VM), IC8.5 (VM), IC10.5 (VM), IC11.5 (VM), IC12.5 (VM), IC13.5 (VM), IC14.5 (VM), IC15.5 (VM), IC16.5 (VM), IC17.5 (VM), IC18.5 (VM); also elsewhere on the board

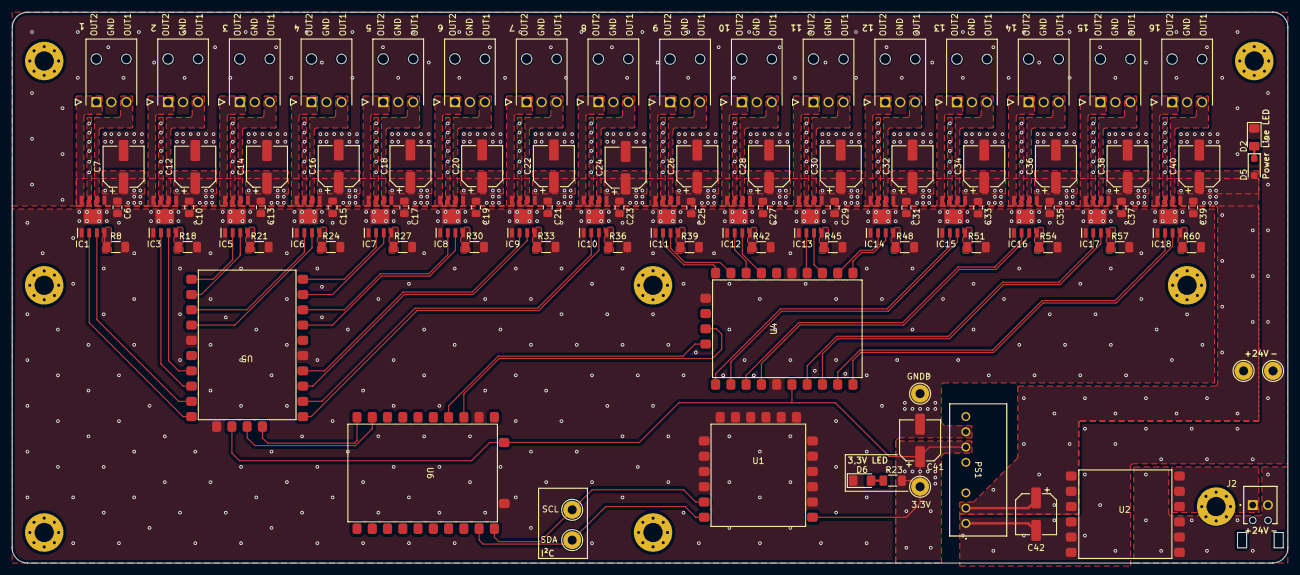
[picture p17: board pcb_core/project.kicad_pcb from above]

Board: 2 copper layers, 212.3 x 91.7 mm, 115 parts (0 on the bottom side), 94 nets.

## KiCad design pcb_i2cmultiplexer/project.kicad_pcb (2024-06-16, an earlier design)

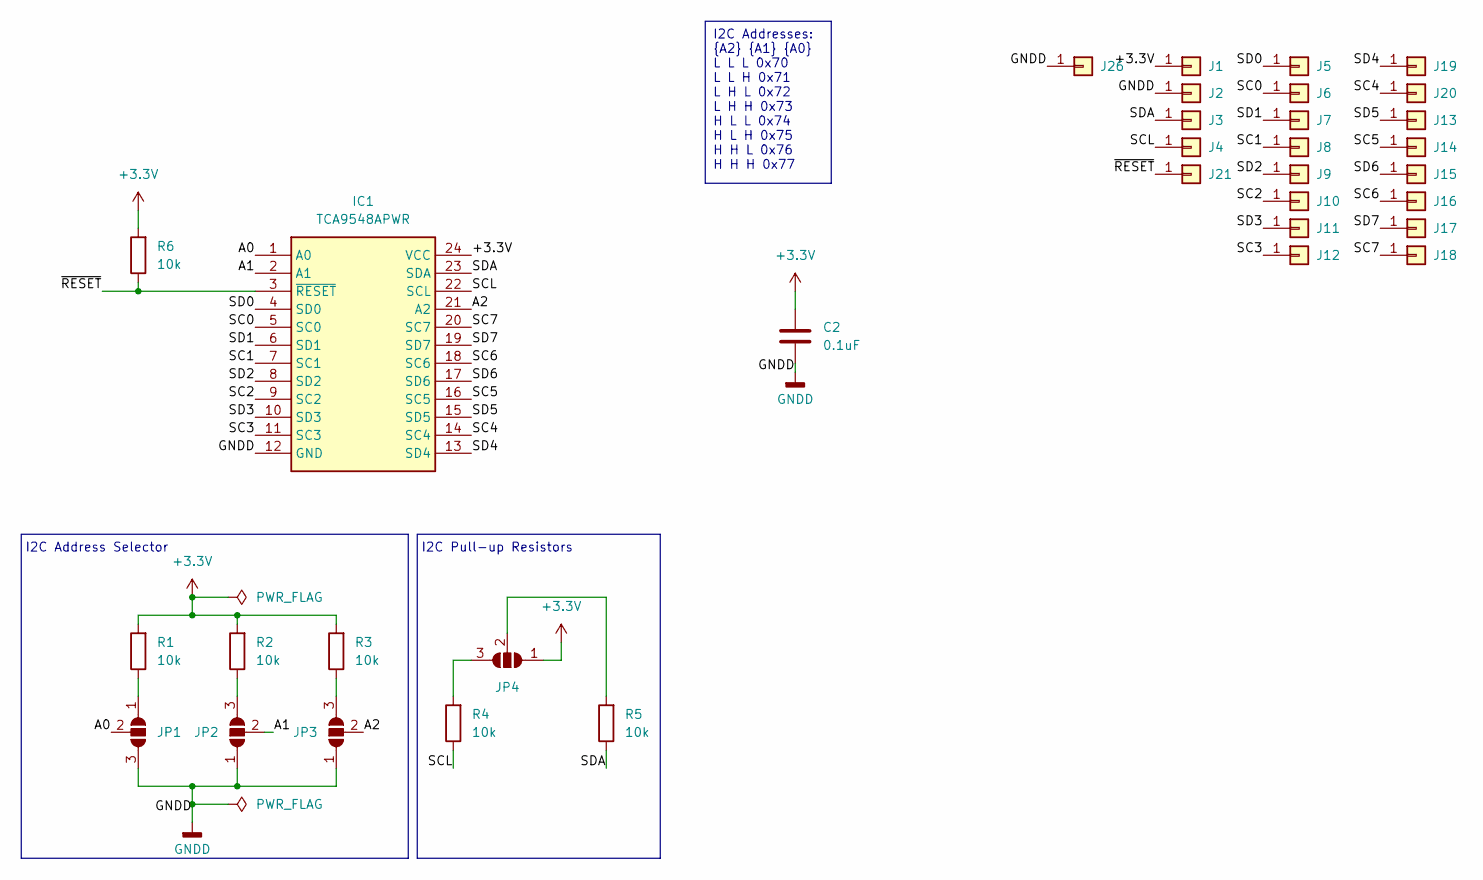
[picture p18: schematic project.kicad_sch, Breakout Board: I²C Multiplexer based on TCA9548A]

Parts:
C2: 0.1uF; C_0402_1005Metric_Pad0.74x0.62mm_HandSolder
IC1: TCA9548APWR; SOP65P640X120-24N; Mouser Part Number 595-TCA9548APWR
J1, J2, J3, J4, J5, J6, J7, J8, J9, J10, J11, J12, J13, J14, J15, J16, J17, J18, J19, J20, J21, J26: Castellated_Hole02
JP1, JP2, JP3, JP4: SolderJumper_3_Open; SolderJumper-3_P1.3mm_Open_RoundedPad1.0x1.5mm
R1, R2, R3, R4, R5, R6: 10k; R_0402_1005Metric_Pad0.72x0.64mm_HandSolder

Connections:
+3.3V: C2.1, IC1.24 (VCC), J1.1, JP4.1 (A), R1.2, R2.2, R3.2, R6.2
/A0: IC1.1 (A0), JP1.2 (C)
/A1: IC1.2 (A1), JP2.2 (C)
/A2: IC1.21 (A2), JP3.2 (C)
/SC0: IC1.5 (SC0), J6.1
/SC1: IC1.7 (SC1), J8.1
/SC2: IC1.9 (SC2), J10.1
/SC3: IC1.11 (SC3), J12.1
/SC4: IC1.14 (SC4), J20.1
/SC5: IC1.16 (SC5), J14.1
/SC6: IC1.18 (SC6), J16.1
/SC7: IC1.20 (SC7), J18.1
/SCL: IC1.22 (SCL), J4.1, R4.1
/SD0: IC1.4 (SD0), J5.1
/SD1: IC1.6 (SD1), J7.1
/SD2: IC1.8 (SD2), J9.1
/SD3: IC1.10 (SD3), J11.1
/SD4: IC1.13 (SD4), J19.1
/SD5: IC1.15 (SD5), J13.1
/SD6: IC1.17 (SD6), J15.1
/SD7: IC1.19 (SD7), J17.1
/SDA: IC1.23 (SDA), J3.1, R5.1
/~RESET: IC1.3 (~RESET), J21.1, R6.1
GNDD: C2.2, IC1.12 (GND), J2.1, J26.1, JP1.3 (B), JP2.1 (A), JP3.1 (A)
unnamed: JP1.1 (A), R1.1
unnamed: JP2.3 (B), R2.1
unnamed: JP3.3 (B), R3.1
unnamed: JP4.3 (B), R4.2
unnamed: JP4.2 (C), R5.2

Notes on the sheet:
I2C Addresses: {A2} {A1} {A0} L L L 0x70 L L H 0x71 L H L 0x72 L H H 0x73 H L L 0x74 H L H 0x75 H H L 0x76 H H H 0x77
I2C Pull-up Resistors
I2C Address Selector

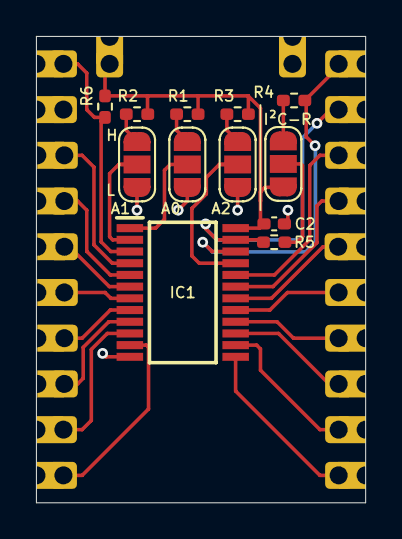
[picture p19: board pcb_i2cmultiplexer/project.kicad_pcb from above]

Board: 2 copper layers, 18.3 x 25.9 mm, 35 parts (1 on the bottom side), 29 nets.

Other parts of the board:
QR*****: https://github.com/fanningert/kicad_pcb_i2cmultip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; //github.com/fanningert/kicad_pcb_i2cmultiplexer

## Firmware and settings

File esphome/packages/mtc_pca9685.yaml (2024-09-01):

defaults:
  hub_no: "1"
  board_no: "1"
  mpc_no: "1"
  ioexp_no: "1"
  i2c_address: '0x40'
  ioexp_freq: '1000'

pca9685:
  - id: h${hub_no}b${board_no}m${mpc_no}i${ioexp_no}
    frequency: ${ioexp_freq}
    i2c_id: h${hub_no}b${board_no}m${mpc_no}
    address: ${i2c_address}

output:
  - platform: pca9685
    pca9685_id: h${hub_no}b${board_no}m${mpc_no}i${ioexp_no}
    channel: 0
    id: h${hub_no}b${board_no}m${mpc_no}i${ioexp_no}_0
  - platform: pca9685
    pca9685_id: h${hub_no}b${board_no}m${mpc_no}i${ioexp_no}
    channel: 1
    id: h${hub_no}b${board_no}m${mpc_no}i${ioexp_no}_1
  - platform: pca9685
    pca9685_id: h${hub_no}b${board_no}m${mpc_no}i${ioexp_no}
    channel: 2
    id: h${hub_no}b${board_no}m${mpc_no}i${ioexp_no}_2
  - platform: pca9685
    pca9685_id: h${hub_no}b${board_no}m${mpc_no}i${ioexp_no}
    channel: 3
    id: h${hub_no}b${board_no}m${mpc_no}i${ioexp_no}_3
  - platform: pca9685
    pca9685_id: h${hub_no}b${board_no}m${mpc_no}i${ioexp_no}
    channel: 4
    id: h${hub_no}b${board_no}m${mpc_no}i${ioexp_no}_4
  - platform: pca9685
    pca9685_id: h${hub_no}b${board_no}m${mpc_no}i${ioexp_no}
    channel: 5
    id: h${hub_no}b${board_no}m${mpc_no}i${ioexp_no}_5
  - platform: pca9685
    pca9685_id: h${hub_no}b${board_no}m${mpc_no}i${ioexp_no}
    channel: 6
    id: h${hub_no}b${board_no}m${mpc_no}i${ioexp_no}_6
  - platform: pca9685
    pca9685_id: h${hub_no}b${board_no}m${mpc_no}i${ioexp_no}
    channel: 7
    id: h${hub_no}b${board_no}m${mpc_no}i${ioexp_no}_7
  - platform: pca9685
    pca9685_id: h${hub_no}b${board_no}m${mpc_no}i${ioexp_no}
    channel: 8
    id: h${hub_no}b${board_no}m${mpc_no}i${ioexp_no}_8
  - platform: pca9685
    pca9685_id: h${hub_no}b${board_no}m${mpc_no}i${ioexp_no}
    channel: 9
    id: h${hub_no}b${board_no}m${mpc_no}i${ioexp_no}_9
  - platform: pca9685
    pca9685_id: h${hub_no}b${board_no}m${mpc_no}i${ioexp_no}
    channel: 10
    id: h${hub_no}b${board_no}m${mpc_no}i${ioexp_no}_10
  - platform: pca9685
    pca9685_id: h${hub_no}b${board_no}m${mpc_no}i${ioexp_no}
    channel: 11
    id: h${hub_no}b${board_no}m${mpc_no}i${ioexp_no}_11
  - platform: pca9685
    pca9685_id: h${hub_no}b${board_no}m${mpc_no}i${ioexp_no}
    channel: 12
    id: h${hub_no}b${board_no}m${mpc_no}i${ioexp_no}_12
  - platform: pca9685
    pca9685_id: h${hub_no}b${board_no}m${mpc_no}i${ioexp_no}
    channel: 13
    id: h${hub_no}b${board_no}m${mpc_no}i${ioexp_no}_13
  - platform: pca9685
    pca9685_id: h${hub_no}b${board_no}m${mpc_no}i${ioexp_no}
    channel: 14
    id: h${hub_no}b${board_no}m${mpc_no}i${ioexp_no}_14
  - platform: pca9685
    pca9685_id: h${hub_no}b${board_no}m${mpc_no}i${ioexp_no}
    channel: 15
    id: h${hub_no}b${board_no}m${mpc_no}i${ioexp_no}_15

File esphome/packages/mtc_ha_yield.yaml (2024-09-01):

# 2 State Yield

defaults:
  hub_no: "1"
  board_no: "1"
  port_no: "1"
  voltage_multi: 1.0
  name: "h${hub_no}b${board_no}p${port_no}_yield"
  delay: 500ms

esphome:
    on_boot:
        priority: 600
        then:
            - binary_sensor.template.publish:
                id: h${hub_no}b${board_no}p${port_no}_yield_state
                state: ON
            - button.press: h${hub_no}b${board_no}p${port_no}_yield

packages:
  yield: !include
    file: mtc_hbridge_voltage.yaml
    vars:
      hub_no: ${hub_no}
      board_no: ${board_no}
      port_no: ${port_no}
      voltage_multi: ${voltage_multi}

binary_sensor:
  - platform: template
    name: ${name} State
    id: h${hub_no}b${board_no}p${port_no}_yield_state
    entity_category: 'DIAGNOSTIC'

button:
  - platform: template
    id: h${hub_no}b${board_no}p${port_no}_yield
    name: "${name}"
    icon: mdi:electric-switch
    on_press:
      then:
        if:
          condition:
            binary_sensor.is_on: h${hub_no}b${board_no}p${port_no}_yield_state
          then:
            - fan.turn_on: 
                id: h${hub_no}b${board_no}p${port_no}_voltage
                speed: 100
                direction: reverse
            - delay: ${delay}
            - fan.turn_off: 
                id: h${hub_no}b${board_no}p${port_no}_voltage
            - binary_sensor.template.publish:
                id: h${hub_no}b${board_no}p${port_no}_yield_state
                state: OFF
          else:
            - fan.turn_on: 
                id: h${hub_no}b${board_no}p${port_no}_voltage
                speed: 100
                direction: forward
            - delay: ${delay}
            - fan.turn_off: 
                id: h${hub_no}b${board_no}p${port_no}_voltage
            - binary_sensor.template.publish:
                id: h${hub_no}b${board_no}p${port_no}_yield_state
                state: ON

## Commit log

2024-04-01 Initial version, migrate from internal gitea repository to github
    [pcb_controller_3d.step, pcb_hbridge_3d.step, pcb_main_3d.step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]
2024-04-01 correct bom columns
    [project.kicad_sch]
2024-04-01 Correct JLCPCB# to LCSC# in BOM
    [project.kicad_sch]
2024-05-04 Change Multi-Board to Single-Board design
    [case-PCBPlaceholder.step, case-Spacer.step, case.FCStd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]
2024-05-04 Add missing netclass and close open connections
    [project.kicad_sch]
2024-05-04 Add missing PWR_FLAGs
    [project.kicad_sch]
2024-05-04 Correct BOM values
    [project.kicad_pcb, project.kicad_sch]
2024-05-04 Correct ERC errors
    [project.kicad_sch]
2024-05-04 Correct BOM errors
    [output_connector.kicad_sch, project.kicad_pcb, project.kicad_sch]
2024-05-04 Correct description field warnings
    [project.kicad_pcb, project.kicad_sch]
2024-05-04 Correct ECR Warnings
    [ioexpender.kicad_sch, output_connector.kicad_sch, project.kicad_pcb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]
2024-05-04 Harmonize package sizing of components
    [ioexpender.kicad_sch, output_connector.kicad_sch, project.kicad_pcb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]
2024-05-04 Update I²C addresses
    [ioexpender.kicad_sch]
2024-05-04 Little style change
    [project.kicad_sch]
2024-05-04 Update BOM
    [ioexpender.kicad_sch, project.kicad_sch]
2024-05-05 Update pcb layout
    [project.kicad_pcb]
2024-05-05 Add Kiri output, correct some output errors
    [project.kicad_sch]
2024-05-05 correct R16 value
    [project.kicad_pcb]
2024-05-05 correct kiri parameter error
    [project.kicad_sch]
2024-05-09 Update pcb, bom and add 3D view
    [project.kicad_pcb, project.kicad_sch]
2024-05-09 Update kiri config and 3D export
    [project.kicad_sch]
2024-05-09 Add blender render
    [project.kicad_pcb]
2024-05-09 Add variants for Master and Slave
    [ioexpender.kicad_sch, output_connector.kicad_sch, project.kicad_pcb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]
2024-05-09 Convert 'config' to 'Config'
    [ioexpender.kicad_sch, output_connector.kicad_sch, project.kicad_pcb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]
2024-05-09 Correct variant setting for components
    [project.kicad_pcb, project.kicad_sch]
2024-05-09 Move location of power line led and set LCSC-IDs
    [project.kicad_pcb, project.kicad_sch]
2024-05-09 Change master,slave to primary and sub node
    [project.kicad_pcb, project.kicad_sch]
2024-05-09 Change workflow, to execute only on kibot config or pcb changes
2024-05-10 Add LED for 3.3V power line
    [project.kicad_pcb, project.kicad_sch]
2024-05-11 Change to I4214DDY-T1-GE3 and update PCB
    [project.kicad_pcb, project.kicad_sch]
2024-05-11 Correct schematic symbol for Current Regulator Diodes, Update Kibot config
    [project.kicad_pcb, project.kicad_sch]
2024-05-11 Optimize PCB
    [project.kicad_pcb]
2024-05-11 Optimize PCB to reduce vias
    [project.kicad_pcb]
2024-05-12 Add AISLER bom support and assigned components
    [ioexpender.kicad_sch, output_connector.kicad_sch, project.kicad_pcb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]
2024-05-23 Update BOM Mouser
    [ioexpender.kicad_sch, output_connector.kicad_sch, project.kicad_pcb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]
2024-06-16 New package version of model train controller
    [ioexpender.kicad_sch, output_connector.kicad_sch, project.kicad_pcb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]
2024-06-16 Remove 3D for panelized PCB
2024-06-16 Add Panelize connector to PCB_Core
    [project.kicad_pcb, project.kicad_sch]
2024-06-16 Optimize cutout rounding
    [project.kicad_pcb]
2024-06-17 Add ESP32Dev PCB
    [project.kicad_pcb, project.kicad_sch]
2024-06-17 Correct ESP32Dev PCB panelize
2024-07-04 Change ioexpander pcb
    [project.kicad_pcb]
